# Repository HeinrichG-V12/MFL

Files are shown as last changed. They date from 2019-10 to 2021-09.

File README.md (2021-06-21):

## Interface für das BMW Multifuktionslenkrad
Kompatibel mit allen BMW MFL, die einen 8-bit Bus verwenden und folgende Belegung haben:
- +12v
- IBus
- Tempomatausgang
- Masse

### Die 16-bit Modelle haben dagegen diese Belegung:
- +12v
- Tastenbeleuchtung
- Datenausgang
- Masse

##### Zu erkennen ist die 16-bit Version auch daran, dass das Fahrzeug zusätzlich ein MFL-Modul verbaut hat.

### Verwendete Bauteile:
- MCU: Microchip Atmega2561
- Spannungsregler: Infineon TLE42754
- IBus-Transceiver: Elmos E910.15
- ADC-Beschaltung: hochohmiger Eingang mit Microchip MCP601 Puffer
- Digital Poti: Microchip MCP42050
- RS-232 Interface: TI MAX232

### Es können folgende Radios gesteuert werden:
- Pioneer/Sony/JVC mit eine RW Eingang
- Becker mit einem RS232 Eingang

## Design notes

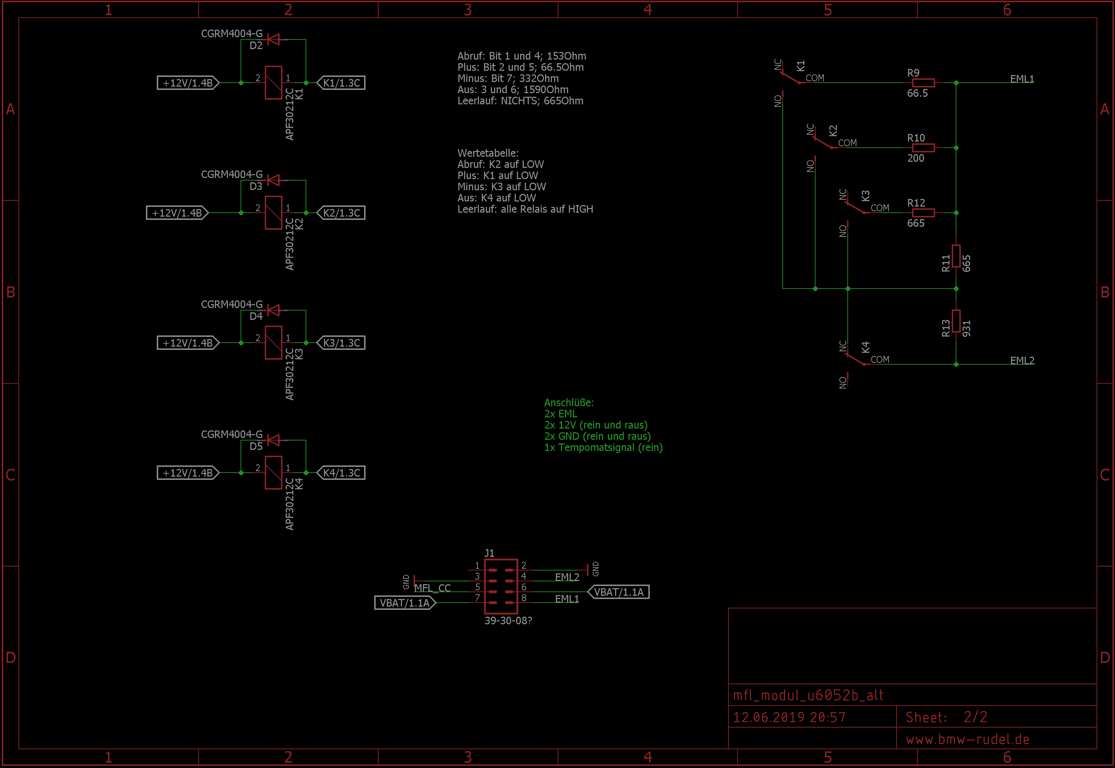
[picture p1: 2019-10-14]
Tempomatmodul_U6052/matrix.png

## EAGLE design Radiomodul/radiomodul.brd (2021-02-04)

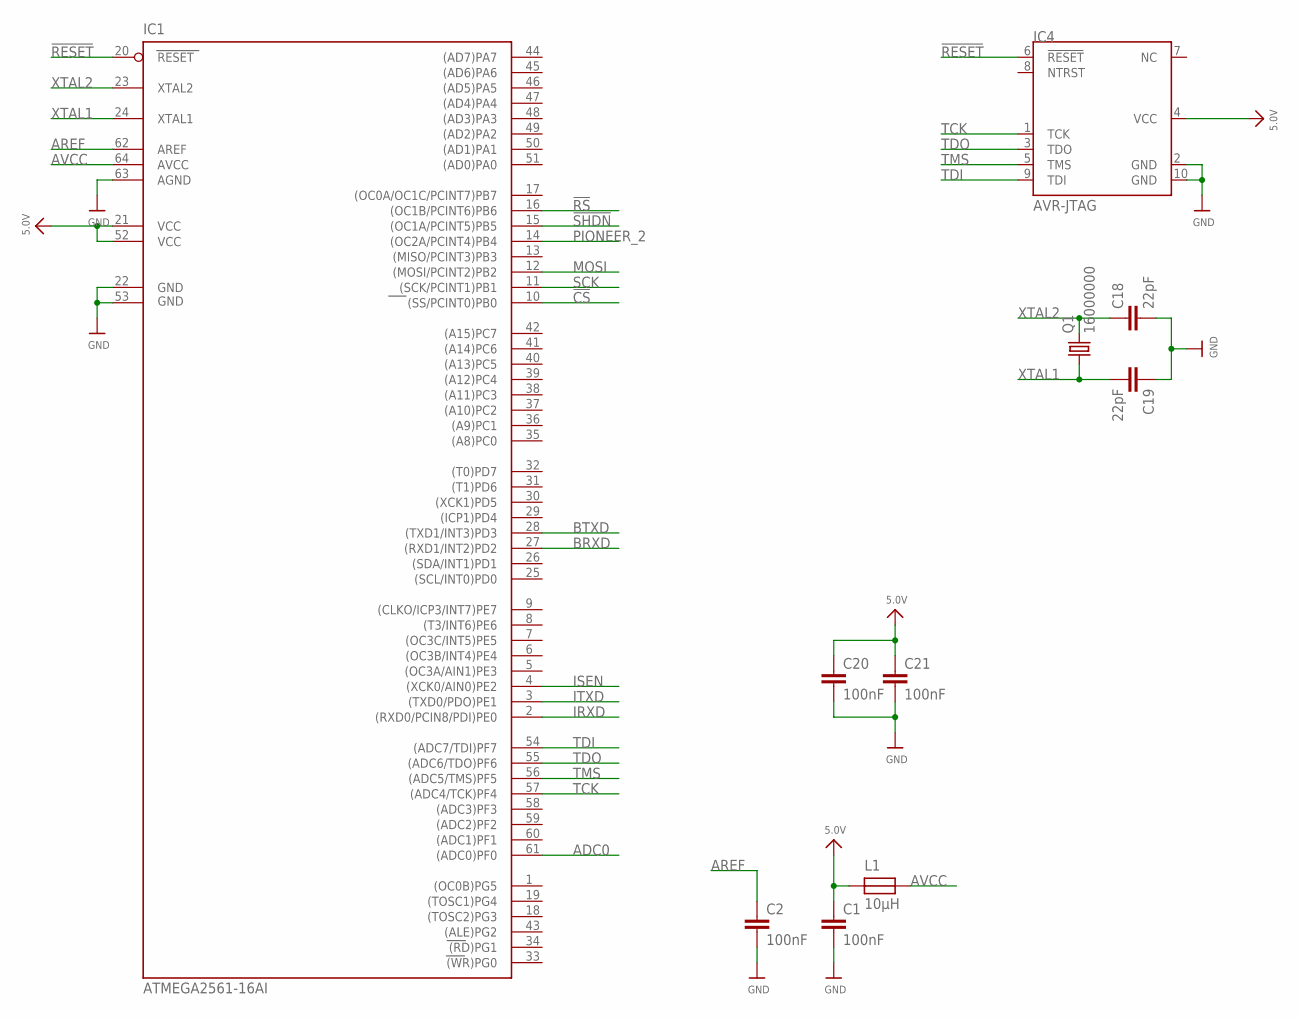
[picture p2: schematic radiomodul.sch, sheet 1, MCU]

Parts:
C1, C2, C20, C21: 100nF; C0805
C18, C19: 22pF; C0805
IC1: ATMEGA2561-16AI; TQFP64
IC4: AVR-JTAG; 2X05_1.27MM_SMT
L1: 10µH; 1206
Q1: 16000000; HC49UP

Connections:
5.0V: C1.1, C20.1, C21.1, IC1.21 (VCC), IC1.52 (VCC1), IC4.4 (VCC), L1.1; also elsewhere on the board
!CS: IC1.10 ((SS/PCINT0)PB0); also elsewhere on the board
!RESET: IC1.20 (RESET), IC4.6 (!RESET); also elsewhere on the board
!RS: IC1.16 ((OC1B/PCINT6)PB6); also elsewhere on the board
!SHDN: IC1.15 ((OC1A/PCINT5)PB5); also elsewhere on the board
ADC0: IC1.61 ((ADC0)PF0); also elsewhere on the board
AREF: C2.1, IC1.62 (AREF)
AVCC: IC1.64 (AVCC), L1.2
BRXD: IC1.27 ((RXD1/INT2)PD2); also elsewhere on the board
BTXD: IC1.28 ((TXD1/INT3)PD3); also elsewhere on the board
GND: C1.2, C2.2, C18.2, C19.1, C20.2, C21.2, IC1.22 (GND), IC1.53 (GND1), IC1.63 (AGND), IC4.2 (GND), IC4.10 (GND); also elsewhere on the board
IRXD: IC1.2 ((RXD0/PCIN8/PDI)PE0); also elsewhere on the board
ISEN: IC1.4 ((XCK0/AIN0)PE2); also elsewhere on the board
ITXD: IC1.3 ((TXD0/PDO)PE1); also elsewhere on the board
MOSI: IC1.12 ((MOSI/PCINT2)PB2); also elsewhere on the board
PIONEER_2: IC1.14 ((OC2A/PCINT4)PB4); also elsewhere on the board
SCK: IC1.11 ((SCK/PCINT1)PB1); also elsewhere on the board
TCK: IC1.57 ((ADC4/TCK)PF4), IC4.1 (TCK)
TDI: IC1.54 ((ADC7/TDI)PF7), IC4.9 (TDI)
TDO: IC1.55 ((ADC6/TDO)PF6), IC4.3 (TDO)
TMS: IC1.56 ((ADC5/TMS)PF5), IC4.5 (TMS)
XTAL1: C19.2, IC1.24 (XTAL1), Q1.1
XTAL2: C18.1, IC1.23 (XTAL2), Q1.2

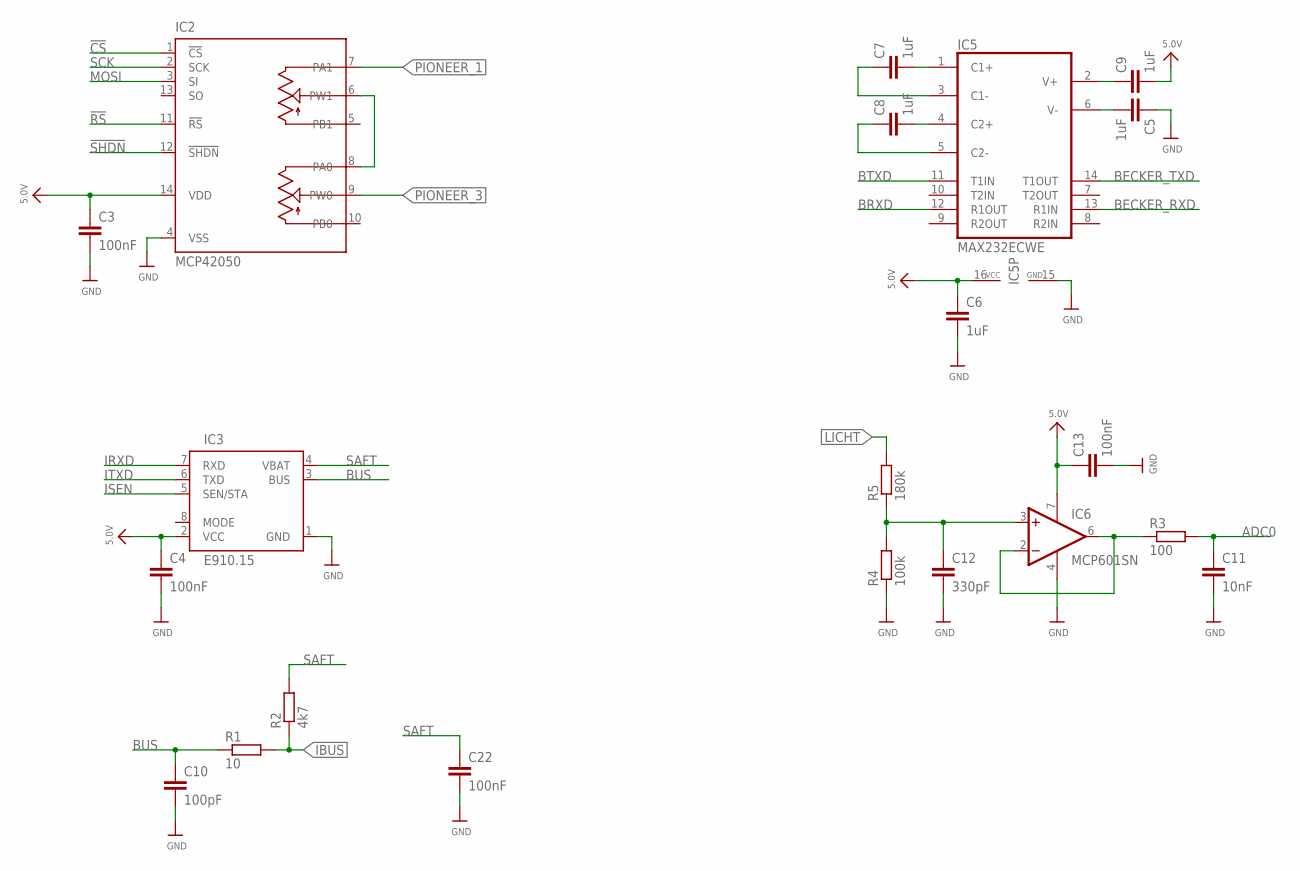
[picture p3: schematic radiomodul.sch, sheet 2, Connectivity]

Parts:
C3, C4, C13, C22: 100nF; C0805
C5, C6, C7, C8, C9: 1uF; C0805
C10: 100pF; C0805
C11: 10nF; C0805
C12: 330pF; C0805
IC2: MCP42050; SO-14
IC3: E910.15; SO8
IC5: MAX232ECWE; SO16L
IC6: MCP601SN; SO08
R1: 10; R0805
R2: 4k7; R0805
R3: 100; R0805
R4: 100k; R0805
R5: 180k; R0805

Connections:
5.0V: C3.1, C4.1, C6.1, C9.2, C13.1, IC2.14 (VDD), IC3.2 (VCC), IC5.16 (VCC), IC6.7 (V+); also elsewhere on the board
!CS: IC2.1 (!CS); also elsewhere on the board
!RS: IC2.11 (!RS); also elsewhere on the board
!SHDN: IC2.12 (!SHDN); also elsewhere on the board
ADC0: C11.1, R3.2; also elsewhere on the board
BECKER_RXD: IC5.13 (R1IN); also elsewhere on the board
BECKER_TXD: IC5.14 (T1OUT); also elsewhere on the board
BRXD: IC5.12 (R1OUT); also elsewhere on the board
BTXD: IC5.11 (T1IN); also elsewhere on the board
BUS: C10.1, IC3.3 (BUS), R1.1
GND: C3.2, C4.2, C5.1, C6.2, C10.2, C11.2, C12.2, C13.2, C22.2, IC2.4 (VSS), IC3.1 (GND), IC5.15 (GND), IC6.4 (V-), R4.1; also elsewhere on the board
IBUS: R1.2, R2.1; also elsewhere on the board
IRXD: IC3.7 (RXD); also elsewhere on the board
ISEN: IC3.5 (SEN/STA); also elsewhere on the board
ITXD: IC3.6 (TXD); also elsewhere on the board
LICHT: R5.2; also elsewhere on the board
MOSI: IC2.3 (SI); also elsewhere on the board
unnamed: C5.2, IC5.6 (V-)
unnamed: C7.1, IC5.3 (C1-)
unnamed: C12.1, IC6.3 (+IN), R4.2, R5.1
unnamed: C8.1, IC5.5 (C2-)
unnamed: IC6.2 (-IN), IC6.6 (OUT), R3.1
unnamed: C8.2, IC5.4 (C2+)
unnamed: IC2.6 (PW1), IC2.8 (PA0)
unnamed: C9.1, IC5.2 (V+)
unnamed: C7.2, IC5.1 (C1+)
PIONEER_1: IC2.7 (PA1); also elsewhere on the board
PIONEER_3: IC2.9 (PW0); also elsewhere on the board
SAFT: C22.1, IC3.4 (VBAT), R2.2; also elsewhere on the board
SCK: IC2.2 (SCK); also elsewhere on the board

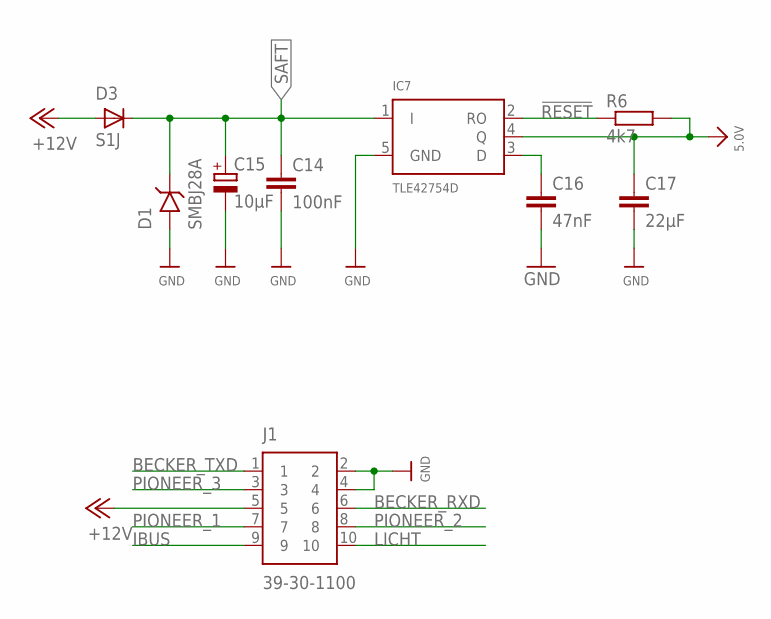
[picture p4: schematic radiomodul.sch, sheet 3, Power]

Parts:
C14: 100nF; C0805
C15: 10µF; PANASONIC_D
C16: 47nF; C0805
C17: 22µF; C1206
D1: SMBJ28A; DO-214AA
D3: S1J; SMADIODE
IC7: TLE42754D; TO252-51
J1: 39-30-1100
R6: 4k7; R0805

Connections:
5.0V: C17.1, IC7.4 (Q), R6.2; also elsewhere on the board
!RESET: IC7.2 (RO), R6.1; also elsewhere on the board
+12V: D3.A, J1.5
BECKER_RXD: J1.6; also elsewhere on the board
BECKER_TXD: J1.1; also elsewhere on the board
GND: C14.2, C15.-, C16.2, C17.2, D1.P$2 (A), IC7.5 (GND), J1.2, J1.4; also elsewhere on the board
IBUS: J1.9; also elsewhere on the board
LICHT: J1.10; also elsewhere on the board
unnamed: C16.1, IC7.3 (D)
PIONEER_1: J1.7; also elsewhere on the board
PIONEER_2: J1.8; also elsewhere on the board
PIONEER_3: J1.3; also elsewhere on the board
SAFT: C14.1, C15.+, D1.P$1 (C), D3.C, IC7.1 (I); also elsewhere on the board

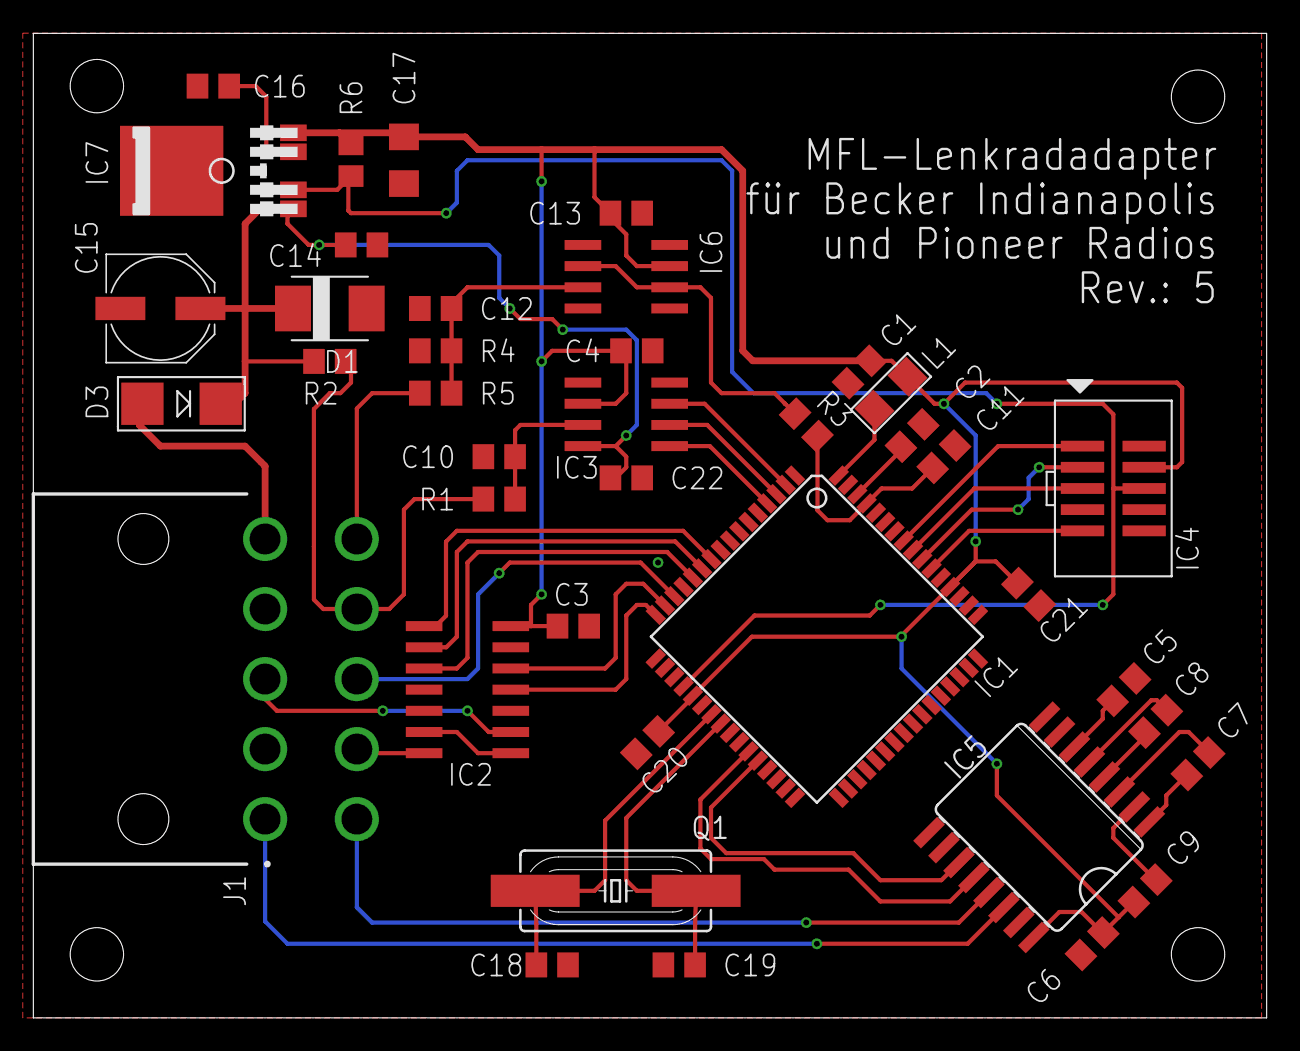
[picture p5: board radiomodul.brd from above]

Board: 2 copper layers, 74.0 x 59.0 mm, 40 parts (0 on the bottom side), 42 nets.

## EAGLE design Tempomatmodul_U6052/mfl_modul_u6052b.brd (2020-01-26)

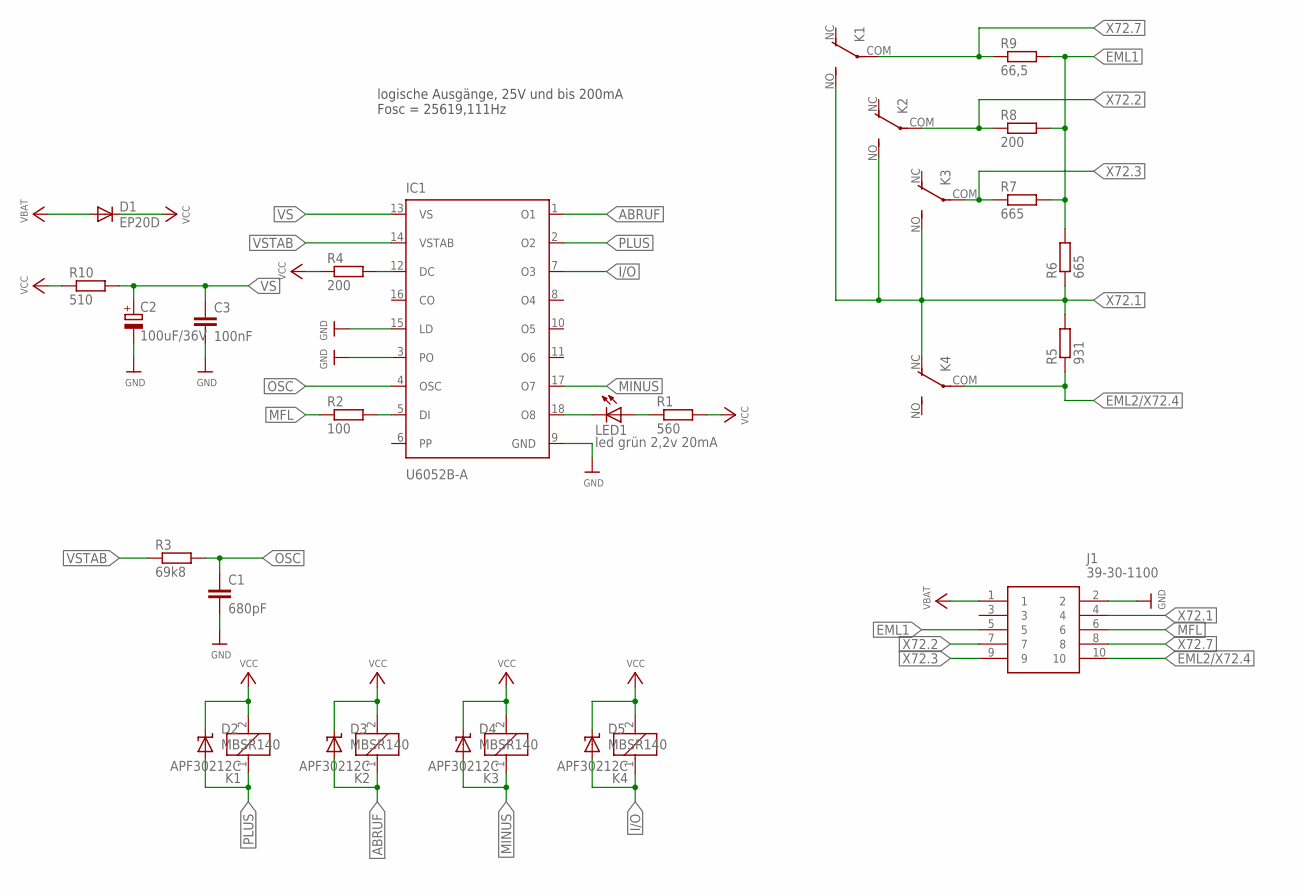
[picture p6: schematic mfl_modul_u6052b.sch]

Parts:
C1: 680pF; C025-025X050
C2: 100uF/36V; E2,5-6
C3: 100nF; C025-025X050
D1: EP20D; DO15-12
D2, D3, D4, D5: MBSR140; DO214AA
IC1: U6052B-A; DIL18
J1: 39-30-1100
K1, K2, K3, K4: APF30212C
LED1: led grün 2,2v 20mA; LED3MM
R1: 560; 0207/7
R2: 100; 0207/7
R3: 69k8; 0207/7
R4, R8: 200; 0207/7
R5: 931; 0207/7
R6, R7: 665; 0207/7
R9: 66,5; 0207/7
R10: 510; 0207/7

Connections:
ABRUF: D3.A, IC1.1 (O1), K2.1
EML1: J1.5, R6.2, R7.2, R8.2, R9.2
EML2/X72.4: J1.10, K4.COM, R5.1
GND: C1.2, C2.-, C3.2, IC1.3 (PO), IC1.9 (GND), IC1.15 (LD), J1.2
I/O: D5.A, IC1.7 (O3), K4.1
MFL: J1.6, R2.1
MINUS: D4.A, IC1.17 (O7), K3.1
unnamed: IC1.5 (DI), R2.2
unnamed: IC1.12 (DC), R4.2
unnamed: LED1.A, R1.1
unnamed: IC1.18 (O8), LED1.K (C)
OSC: C1.1, IC1.4 (OSC), R3.2
PLUS: D2.A, IC1.2 (O2), K1.1
VBAT: D1.A, J1.1
VCC: D1.C, D2.C, D3.C, D4.C, D5.C, K1.2, K2.2, K3.2, K4.2, R1.2, R4.1, R10.1
VS: C2.+, C3.1, IC1.13 (VS), R10.2
VSTAB: IC1.14 (VSTAB), R3.1
X72.1: J1.4, K1.NO (S), K2.NO (S), K3.NO (S), K4.NC (O), R5.2, R6.1
X72.2: J1.7, K2.COM, R8.1
X72.3: J1.9, K3.COM, R7.1
X72.7: J1.8, K1.COM, R9.1

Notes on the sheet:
logische Ausgänge, 25V und bis 200mA Fosc = 25619,111Hz

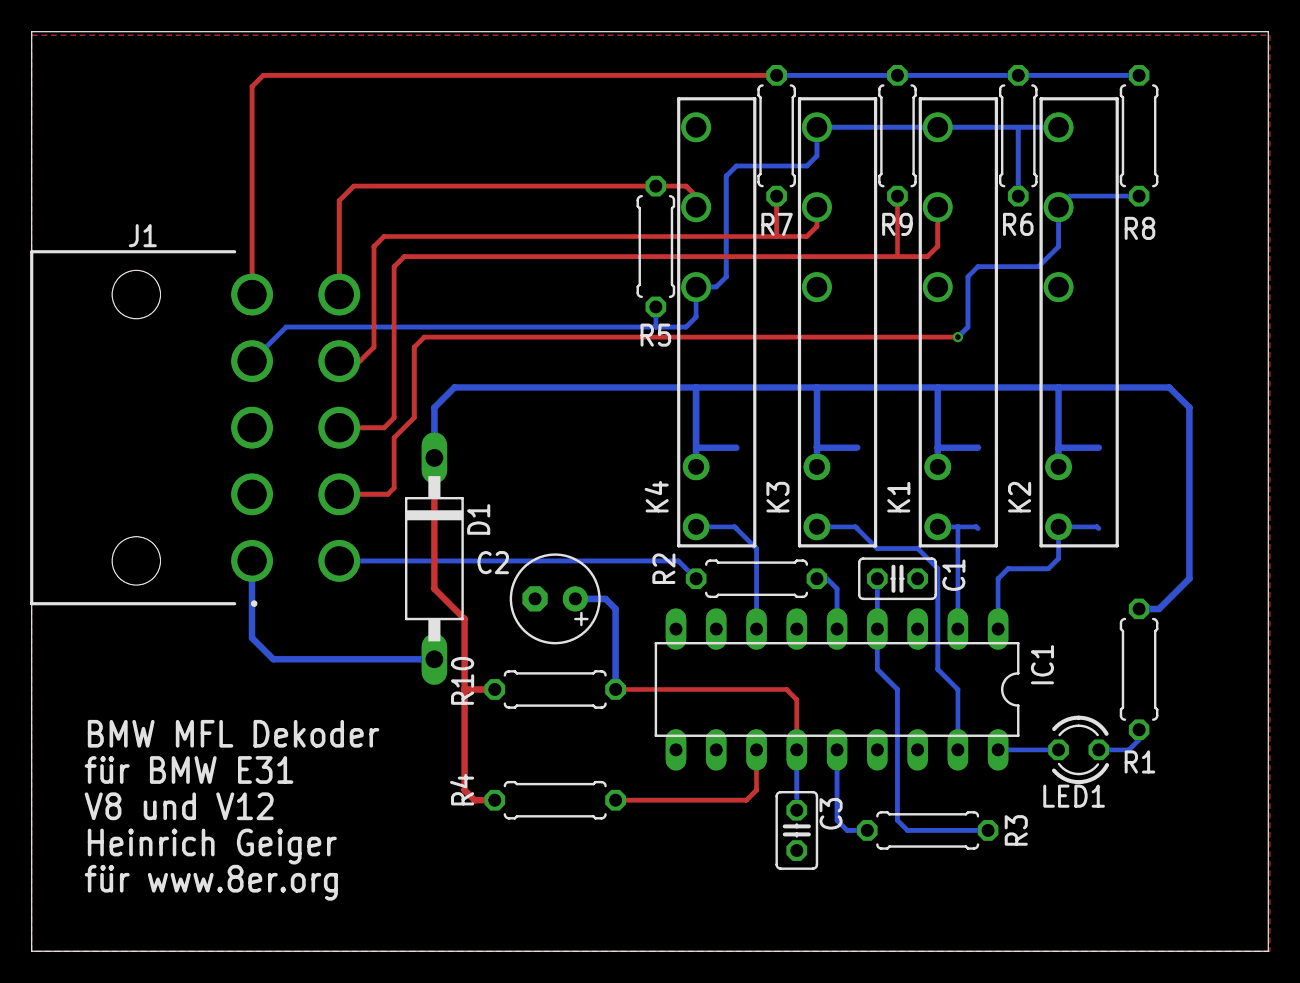
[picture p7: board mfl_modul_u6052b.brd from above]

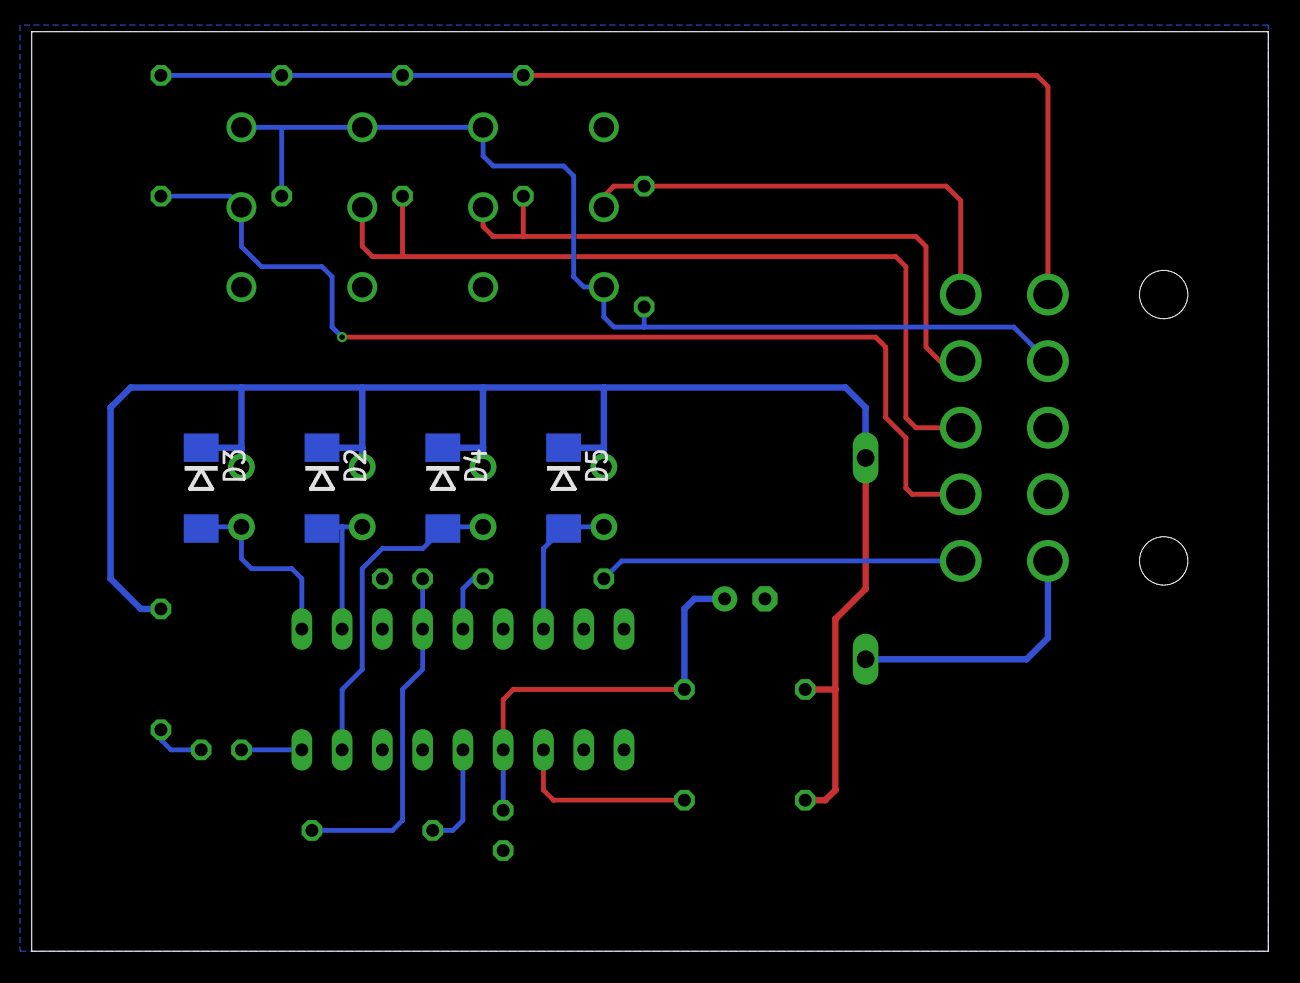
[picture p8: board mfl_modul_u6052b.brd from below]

Board: 2 copper layers, 78.0 x 58.0 mm, 25 parts (4 on the bottom side), 21 nets.

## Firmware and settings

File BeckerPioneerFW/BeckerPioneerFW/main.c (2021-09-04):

/*
 * Radio.c
 *
 * Created: 21.03.2020 10:22:28
 *  Author: Heinrich
 */

#ifndef F_CPU
/* Definiere F_CPU, wenn F_CPU nicht bereits vorher definiert 
   (z.B. durch Übergabe als Parameter zum Compiler innerhalb 
   des Makefiles). Zusätzlich Ausgabe einer Warnung, die auf die
   "nachträgliche" Definition hinweist */
#warning "F_CPU war noch nicht definiert, wird nun mit 16MHz definiert"
#define F_CPU 16000000UL     /* Quarz mit 16 Mhz */
#endif

#include <avr/io.h>
#include "core/core.h"
#include "adc/adc.h"
#include "ibus_processor/ibus_processor.h"
#include "radio_control/radio_controller.h"

int main(void)
{
	uint8_t* msg;
	uint8_t depth = 0;
	
	ports_pins_init();
	spi_init();
	// adc_init();
	ibus_init();
	controller_init();
	sei();

    while (1)
    {
		depth = rx_buffer_get_depth();
		
		if (depth > 0)
		{
			msg = rx_buffer_get_entry();			
			ibus_processor(msg);
			rx_buffer_remove_entry();
		}
    }
	
	while(1){}
}

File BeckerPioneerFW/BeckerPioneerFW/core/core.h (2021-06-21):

/*
 * core.h
 *
 * Created: 20.06.2021 20:08:32
 *  Author: Heinrich
 */ 

#include <avr/io.h>

#ifndef CORE_H_
#define CORE_H_

// digipot ports and pins
#define MCP_HW_INT			DDRB
#define MCP_HW_INT_PORT		PORTB
#define RING				PB4
#define MCP_SHDN			PB5
#define MCP_RST				PB6

// spi ports and pins
#define DDR_CS				DDRB
#define DDR_SPI				DDRB
#define DD_CS				PB0
#define DD_SCK				PB1
#define DD_MOSI				PB2

void ports_pins_init (void);



#endif /* CORE_H_ */

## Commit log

2019-05-01 initial import
    [ecu.brd, ecu.sch, mfl_modul_u6052b.brd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]
2019-10-14 Fixed. Running version!
    [mfl_modul_u6052b.brd, mfl_modul_u6052b.sch, mfl_modul_u6052b.xlsx]
2019-10-28 Fosc corrected
    [mfl_modul_u6052b.brd, mfl_modul_u6052b.sch, mfl_modul_u6052b.xlsx]
2019-11-01 add adc lib add set_brigh function for setting brightness of mfl illumination
2019-11-02 added ad5243 added ibus_network some corrections and refactorings
    [ibus.c]
2019-11-07 timer added some refactorings in uart
2019-11-13 the name corrected
    [ecu.brd, ecu.sch, radiomodul.sch]
2020-01-03 Added support for V8 engines (M60 and M62)
    [mfl_modul_u6052b.brd, mfl_modul_u6052b.sch]
2020-03-21 MFL Radio interface done.
    [radiomodul.brd, radiomodul.sch]
2020-04-04 some changes in SPI
    [Berechnungen.xlsx]
2020-04-05 changed F_CPU to 16000000Hz
    adapted timer to new F_CPU
    adapted UARTs to new F_CPU
    start implementation of ibus processor
    created radio_controller interface
    calculated values for pioneer radio
    [Berechnungen.xlsx]
2020-04-06 some parts changed, BOM added
    [radiomodul.brd, radiomodul.sch, radiomodul_bom.xlsx]
2020-04-06 interrupt to receive ibus messages implemented
2020-04-24 working version!
    [Berechnungen.xlsx]
2020-04-24 adc_activated
    set_brightness corrected
    some clean ups
    [adc.c, main.c]
2020-04-27 UART1 fixed
    asynchronous communication with radios improved
    release corrected
    ibus_processor corrected
    some refactorings
    [Berechnungen.xlsx]
2020-04-28 pioneer 2 added
    AD5293 added
    MCP42050 removed
    [Berechnungen.xlsx]
2020-04-30 adc offset added
    300ms scheduler timer implemented
    sen/sta pin handling corrected / ibus sending routine
    [Berechnungen.xlsx]
2020-05-25 a lot of changes....
    tested functions of MFL:
    -> volume increase and decrease
    -> next and previous track
    [Berechnungen.xlsx, radiomodul.sch]
2020-06-07 some AD5293 functions implemented
    some small bugfixes
    [Berechnungen.xlsx]
2020-12-30 Migrated to new Atmel Studio version
    [Berechnungen.xlsx]
2021-01-23 -> removed ad5293 libraries -> added handling for hardware reset and shutdown -> some small refactorings
    [adc.c]
2021-02-04 board and schematic replaced
    [radiomodul.brd, radiomodul.sch, radiomodul_bom.xlsx]
2021-06-21 implemented hw control of mcp42xxx added core pin init
2021-06-22 TIMER4 fixed, some clean ups
    [Berechnungen.xlsx]

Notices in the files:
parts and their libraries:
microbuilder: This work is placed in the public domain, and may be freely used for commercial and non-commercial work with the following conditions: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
